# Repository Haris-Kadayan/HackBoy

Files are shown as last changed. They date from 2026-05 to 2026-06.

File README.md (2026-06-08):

HACK BOY Cover 43

Hack Boy
-

Hack Boy is a hackpad (macropad) designed to look like the original Game Boy. It has 4 keys, a rotary encoder, an OLED display, and RGB underglow. It is based on QMK firmware and is created for the Hack Club Stasis program.

I made this because I always wanted a macropad for my personal use. However, I did not want it to look like a generic box, so I decided to go with the Game Boy design for it to stand out. It was also a good chance for me to practice my KiCad, Fusion 360, and C skills.

Features
-
* 4x Cherry MX Keys
* 1x EC11 Rotary Encoder
* 1x 0.91" 128x32 OLED Display
* 6x SK2812 MINI-E LEDs
* 1x Seeed Studio XIAO RP2040

CAD
-
I designed the case in Fusion 360. It is a two part case held together using 4 M3 screws and heat set inserts. The deisgn pays homage to the original Game Boy, with realistic grooves, placement, fake buttons, logo, and speaker grille.



Schematic and PCB
-
I designed the schematic and PCB in KiCad. The schematic took the least time. The PCB took much longer. I designed the graphics in Canva and exported it in SVG format. I probably should have added an LED for the top and bottom. Speaking of LEDs, they were a pain to wire, i had to rewire it multiple times to fit all of them. I added holes for allignment but never used them.





Firmware
-
Uses QMK firmware. Here are the functions:
* top left: Copy
* top right: Cut
* encoder press: Mute
* bottom left: Paste
* bottom right: Undo
* encoder turn: Volume up/down

Had some weird compile issue with the LED drivers, but it was fixed with:
WS2812_DRIVER = vendor



BOM:
-
(JLCPCB has a 2 dollar coupon and AliExpress has a 3 dollar coupon, which is why the funding amount is 5 dollars lower than the BOM total):
(not listed in Stasis BOM because I already have these):

* 4x M3x5x5.5 Heat Set Inserts
* 4x M3 Screws

| Name | Purpose | Quantity | Total Cost (USD) | Link | Distributor |
|---|---|---|---|---|---|
| 0.91"" 128x32 OLED Display | Display text and animations | 1 | 4.07 | https://www.aliexpress.us/item/3256807013199079.html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 | AliExpress  |
| 10 PCS DSA Black Keycaps | Covers the key switches | 1 | 2.7 | https://www.aliexpress.us/item/3256810533781399.html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 | AliExpress  |
| PCB | Connects all the components | 1 | 2 | https://cart.jlcpcb.com/quote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 | JLCPCB |
| SK6812-E MINI-E LEDs | Lights up the macropad | 1 | 2.43 | https://www.aliexpress.us/item/3256805007401420.html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 | AliExpress  |
| EC11 Rotary Encoder 5 PCS | Input knob | 1 | 3.24 | https://www.aliexpress.us/item/3256808530463909.html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 | AliExpress  |
| 20 PCS Brown Switch | Input button | 1 | 0.99 | https://www.aliexpress.us/item/3256811652574937.html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 | AliExpress  |
| Seeed Studio XIAO RP2040 | Controls the macropad | 1 | 9.99 | https://www.amazon.com/Microcontroller-Dual-Core-MicroPython-CircuitPython-Interfaces/dp/B09NNVNW7M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 | Amazon |
| 4x M3x5x5.5 Heat Set Inserts | Where the M3 screws thread into | 1 | Already own | | |
| 4x M3 Screws | To attach the body and lid | 1 | Already own | | |

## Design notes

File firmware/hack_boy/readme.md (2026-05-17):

# Overview

Hi, my name is Haris Kadayan and I built Hack Boy which is a Game Boy themed macropad built for Hack Club Blueprint.

Bascially, Hack Boy is a macropad with
- 4 Cherry MX Switches
- Rotary encoder with button
- 0.91 inch SSD1306 OLED display
- 6 SK6812 MINI-E RGB LEDs
- Seeed Studio XIAO RP2040

# Main features

- It has 4 keys
- Encoder controls volume
- When you press the encoder, it will mute the volume
- When it boots, it says Hack Boy v1.1, then By: Haris K., then shows the current volume. If it is muted, it shows Muted.
- Left key:
- LEDs default to red (for now :)

# To compile it

Just run this:
qmk compile -kb hack_boy -km default

# To flash it

I think this is it:
Put the xiao into bootloader mode and drag the final .uf2 file onto it.

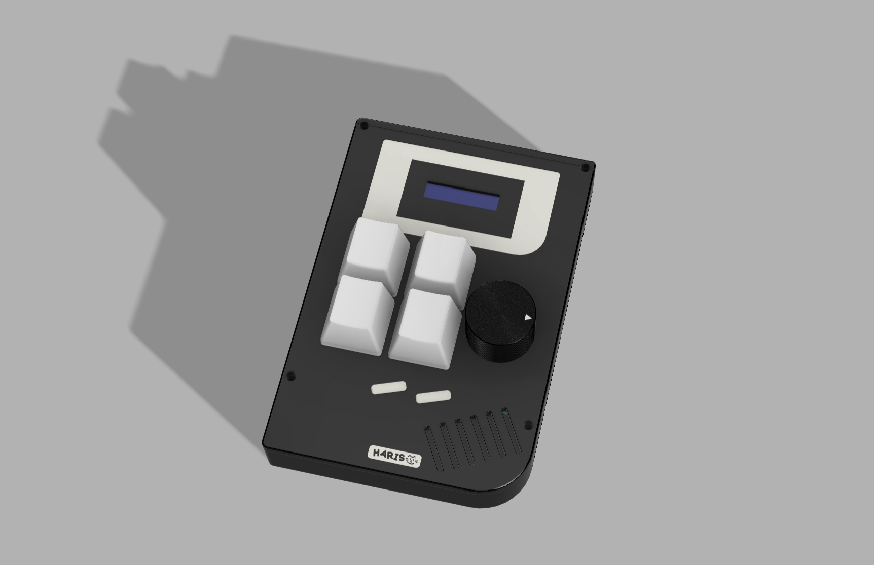
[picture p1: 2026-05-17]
images/Screenshot 2026-05-17 112629.png

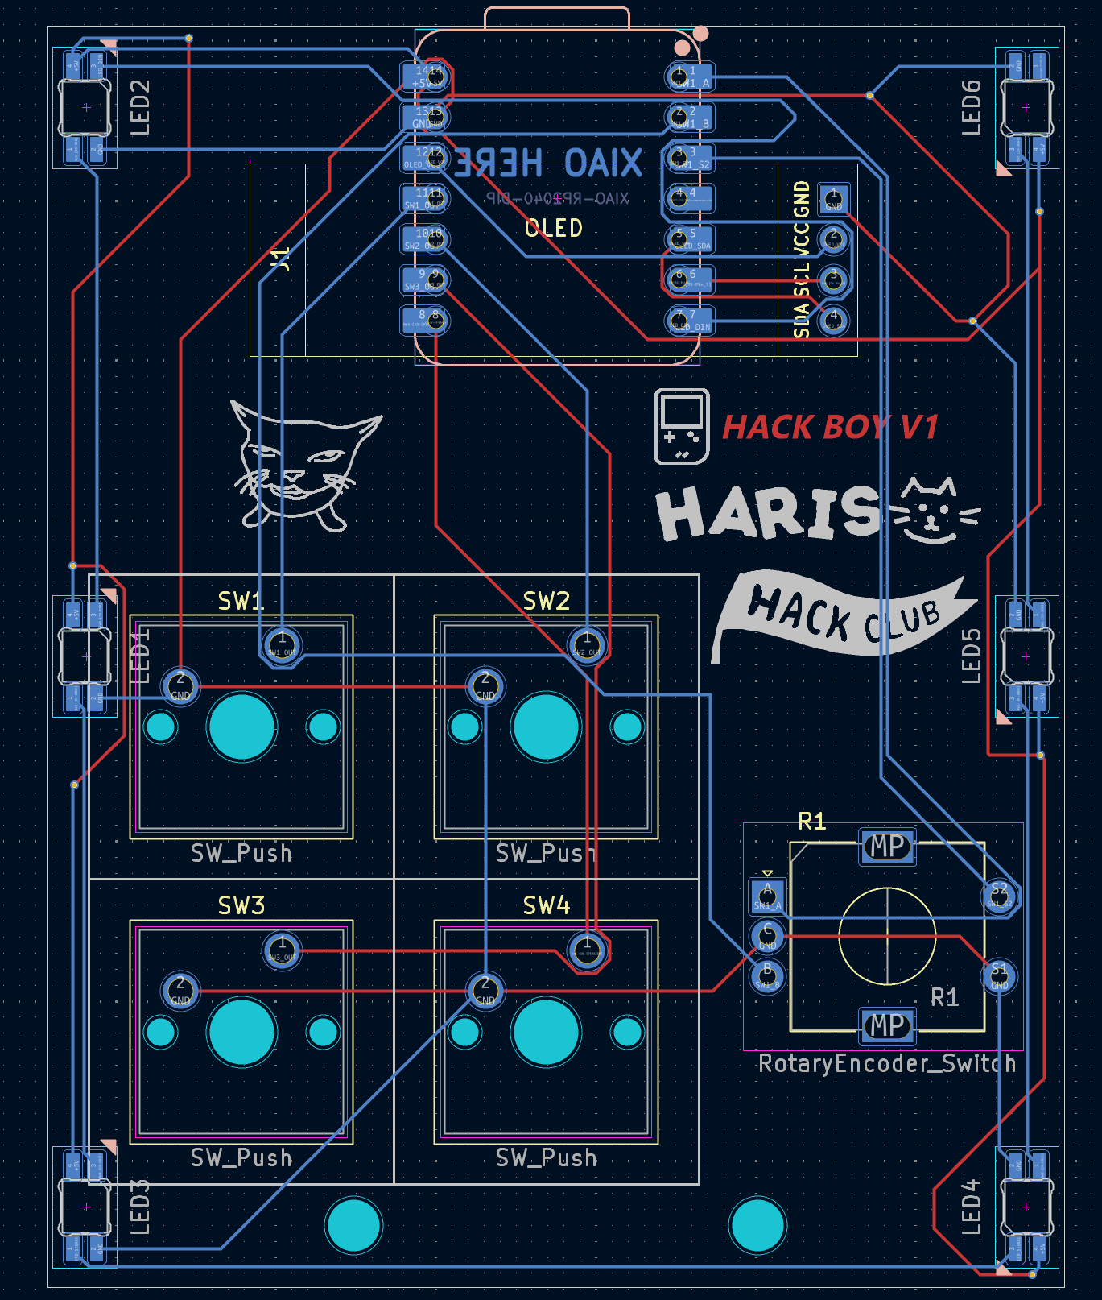
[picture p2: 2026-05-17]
images/image.png

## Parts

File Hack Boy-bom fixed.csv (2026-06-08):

Name | Purpose | Quantity | Total Cost (USD) | Link | Distributor
0.91" 128x32 OLED Display | Display text and animations | 1 | 4.07 | https://www.aliexpress.us/item/3256807013199079.html?curPageLogUid=ILeZHAD4BSke | AliExpress
10 PCS DSA Black Keycaps | Covers the key switches | 1 | 2.7 | https://www.aliexpress.us/item/3256810533781399.html?curPageLogUid=EOFkWa1pLd43 | AliExpress
PCB | Connects all the components | 1 | 2 | https://cart.jlcpcb.com/quote?stencilLayer=2&stencilWidth=100&stencilLength=100&stencilCounts=5&plateType=1 | JLCPCB
SK6812-E MINI-E LEDs | Lights up the macropad | 1 | 2.43 | https://www.aliexpress.us/item/3256805007401420.html?src=google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 | AliExpress
EC11 Rotary Encoder 5 PCS | Input knob | 1 | 3.24 | https://www.aliexpress.us/item/3256808530463909.html?mp=1 | AliExpress
20 PCS Brown Switch | Input button | 1 | 0.99 | https://www.aliexpress.us/item/3256811652574937.html?mp=1 | AliExpress
Seeed Studio XIAO RP2040 | Controls the macropad | 1 | 9.99 | https://www.amazon.com/Microcontroller-Dual-Core-MicroPython-CircuitPython-Interfaces/dp/B09NNVNW7M | Amazon
4x M3x5x5.5 Heat Set Inserts | Where the M3 screws thread into | 1 | Already own
4x M3 Screws | To attach the body and lid | 1 | Already own

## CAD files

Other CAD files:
cad/Hack Boy Assembly.step
cad/Hack Boy Enclosure.f3d

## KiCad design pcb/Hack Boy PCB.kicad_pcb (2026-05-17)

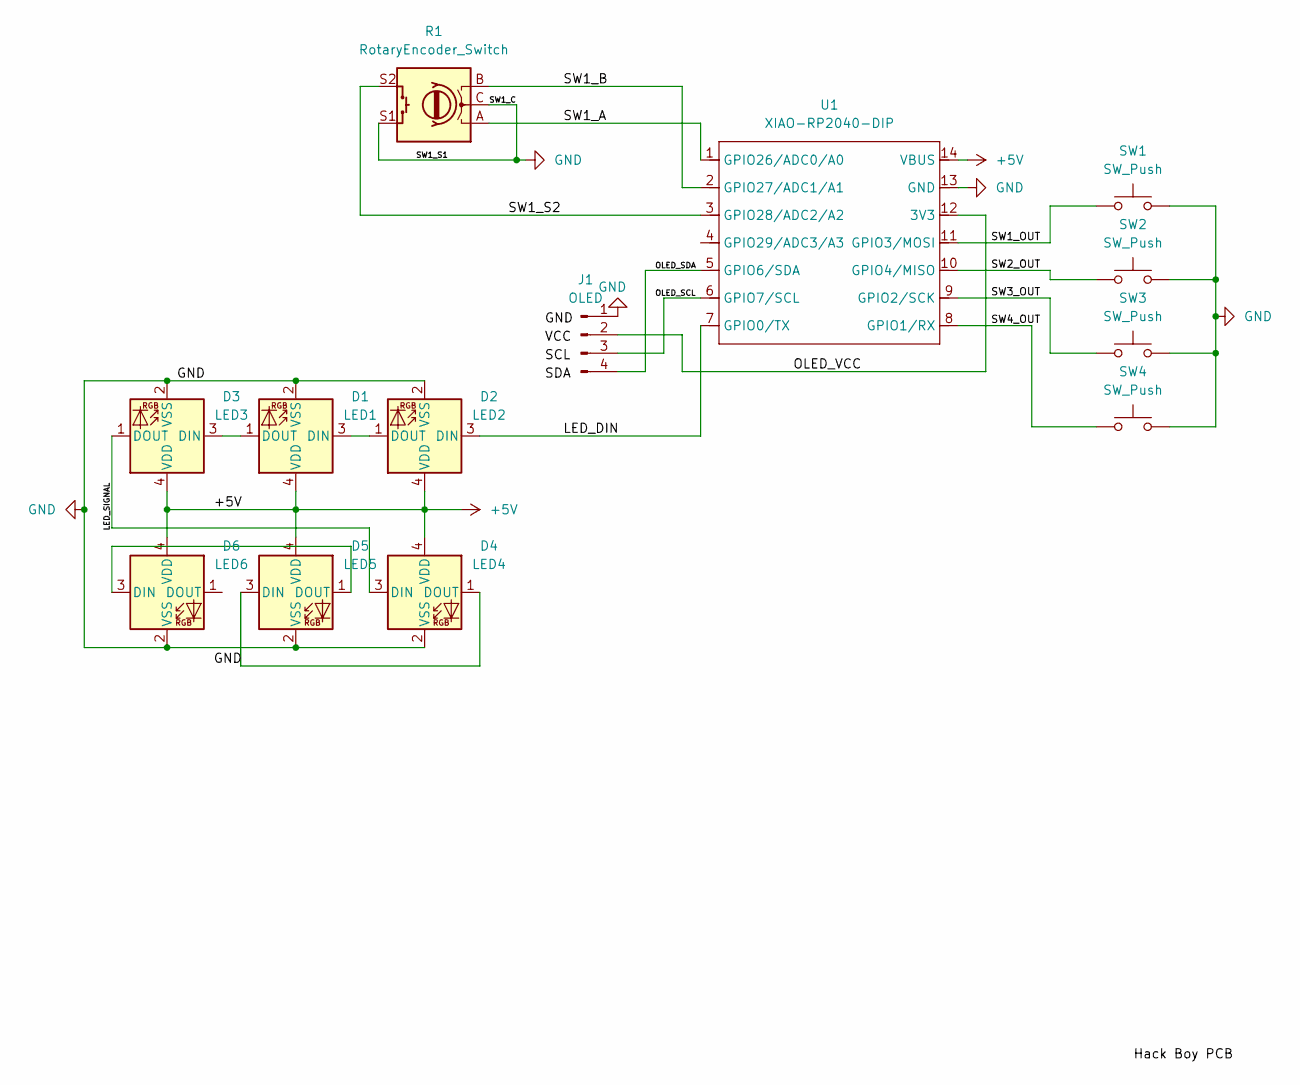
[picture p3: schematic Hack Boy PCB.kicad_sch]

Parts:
D1: LED1; SK6812MINI-E_fixed
D2: LED2; SK6812MINI-E_fixed
D3: LED3; SK6812MINI-E_fixed
D4: LED4; SK6812MINI-E_fixed
D5: LED5; SK6812MINI-E_fixed
D6: LED6; SK6812MINI-E_fixed
J1: OLED; SSD1306-0.91-OLED-4pin-128x32
R1: RotaryEncoder_Switch; RotaryEncoder_Alps_EC11E-Switch_Vertical_H20mm
SW1, SW2, SW3, SW4: SW_Push; SW_Cherry_MX_1.00u_PCB
U1: XIAO-RP2040-DIP

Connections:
+5V: D1.4 (VDD), D2.4 (VDD), D3.4 (VDD), D4.4 (VDD), D5.4 (VDD), D6.4 (VDD), U1.14 (VBUS)
/LED_DIN: D2.3 (DIN), U1.7 (GPIO0/TX)
/LED_SIGNAL: D3.1 (DOUT), D4.3 (DIN)
/OLED_SDA: J1.4, U1.5 (GPIO6/SDA)
/OLED_VCC: J1.2, U1.12 (3V3)
/SW1_A: R1.A, U1.1 (GPIO26/ADC0/A0)
/SW1_B: R1.B, U1.2 (GPIO27/ADC1/A1)
/SW1_OUT: SW1.1, U1.11 (GPIO3/MOSI)
/SW1_S2: R1.S2, U1.3 (GPIO28/ADC2/A2)
/SW2_OUT: SW2.1, U1.10 (GPIO4/MISO)
/SW3_OUT: SW3.1, U1.9 (GPIO2/SCK)
GND: D1.2 (VSS), D2.2 (VSS), D3.2 (VSS), D4.2 (VSS), D5.2 (VSS), D6.2 (VSS), J1.1, R1.C, R1.S1, SW1.2, SW2.2, SW3.2, SW4.2, U1.13 (GND)
unnamed: D1.3 (DIN), D2.1 (DOUT)
unnamed: D1.1 (DOUT), D3.3 (DIN)
unnamed: D4.1 (DOUT), D5.3 (DIN)
unnamed: D5.1 (DOUT), D6.3 (DIN)
unnamed: J1.3, U1.6 (GPIO7/SCL)
unnamed: SW4.1, U1.8 (GPIO1/RX)

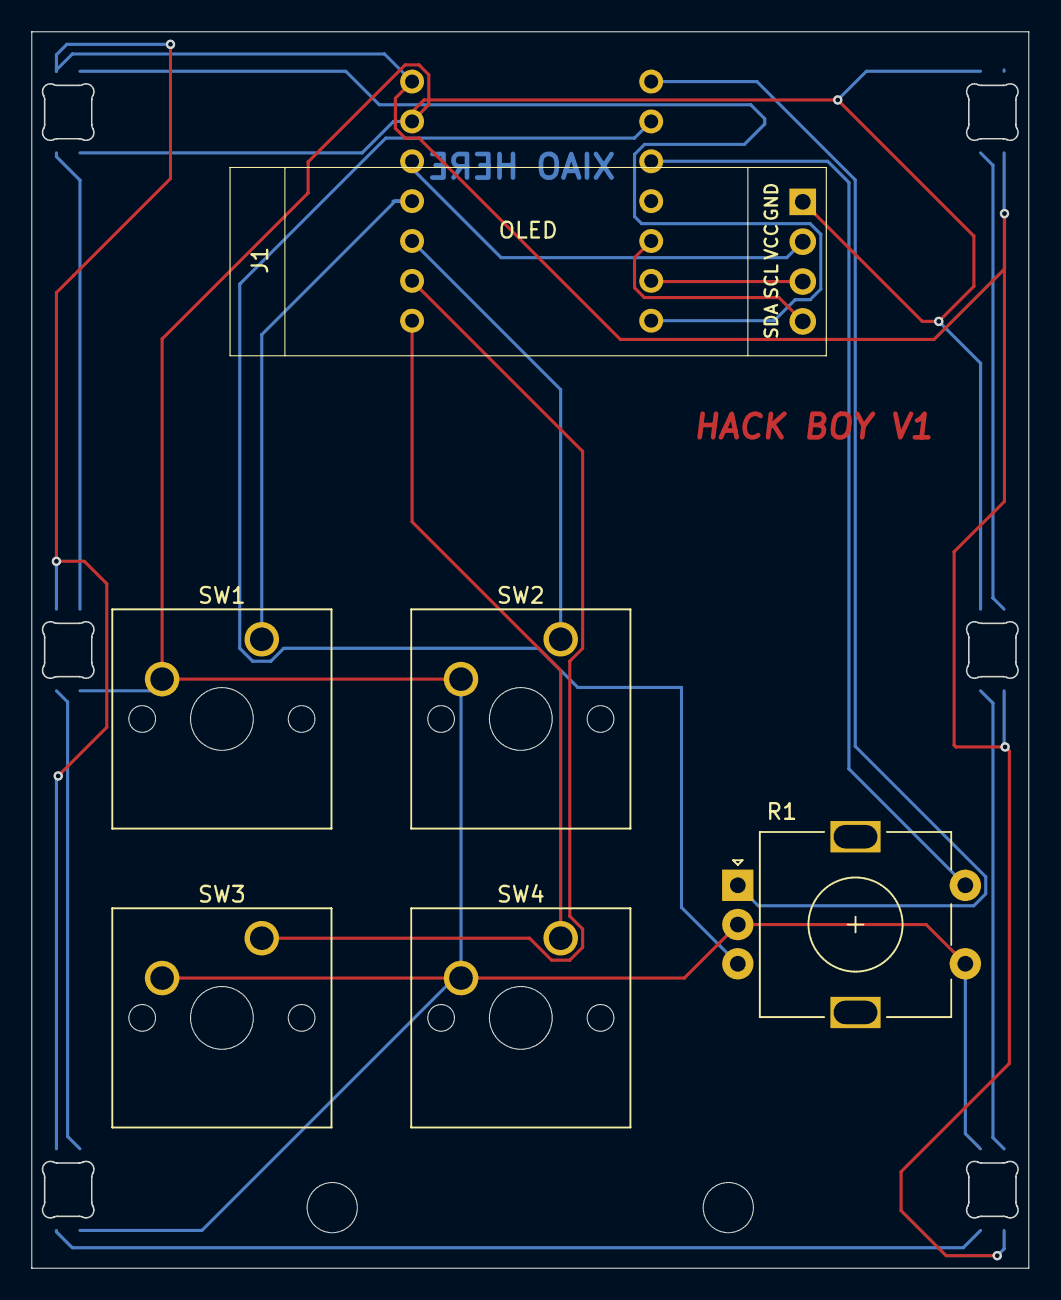
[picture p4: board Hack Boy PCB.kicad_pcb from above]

Board: 2 copper layers, 63.5 x 78.8 mm, 14 parts (1 on the bottom side), 18 nets.

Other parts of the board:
REF: AlignHole_1p6mm

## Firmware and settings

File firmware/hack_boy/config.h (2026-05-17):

#pragma once

#define ENCODER_RESOLUTION 4

#define WS2812_DI_PIN GP0
#define RGBLIGHT_LED_COUNT 6

#define I2C_DRIVER I2CD1
#define I2C1_SDA_PIN GP6
#define I2C1_SCL_PIN GP7

#define OLED_TIMEOUT 30000
#define OLED_BRIGHTNESS 120

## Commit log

2026-04-07 Enhance README with detailed project information
    Expanded the README to include detailed information about the Hack Boy, its features, CAD design, schematic and PCB design, firmware functions, and BOM.
2026-05-17 Rename Hack Boy Assembly.zip to Hack Boy Assembly STEP.zip
2026-05-17 Rename Hack Boy Enclosure.zip to Hack Boy Enclosure f3z.zip
2026-05-17 Add CAD files with Git LFS
    [Hack Boy Assembly.step, Hack Boy Enclosure.f3d]
2026-05-23 Update BOM section in README.md
    Removed specific BOM items that are no longer needed.
2026-05-23 Update BOM section with coupon information
